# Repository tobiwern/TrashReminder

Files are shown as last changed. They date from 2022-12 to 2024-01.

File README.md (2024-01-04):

# Müll-Erinnerung ("Trash Reminder")

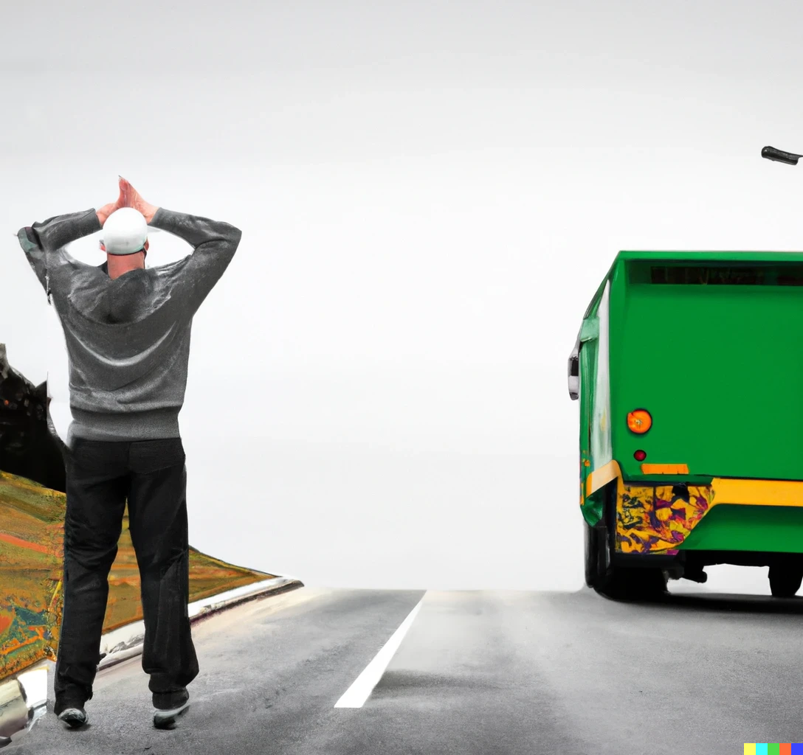
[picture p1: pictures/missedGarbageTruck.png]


**Schon mal vergessen den Mülleimer rauszustellen?**

`Müll-Erinnerung` erinnert Dich daran, indem es eine farbig blinkende Erinnerung anzeigt.

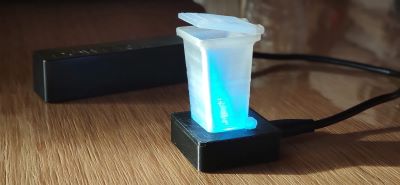
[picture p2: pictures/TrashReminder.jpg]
bild


Je nach Müllart blinkt das Mülleimermodell in einer unterschiedlichen Farbe:
- `weiß`: Restmüll
- `blau`: Papier
- `grün`: Biomüll/Häckselgut
- `gelb`: Gelber Sack oder Wertstofftonne

Wird also zum Beispiel `Restmüll` abgeholt, blinkt das Mülleimermodell `weiß`.

Sollten am selben Tag **zwei** unterschiedliche Müllarten abgeholt werden, wechselt das Licht zwischen den entsprechenden Farben hin und her. Also zum Beispiel zwischen `weiß` und `grün`, wenn sowohl `Restmüll` als auch `Biomüll` am selben Tag abgeholt werden.

## Einrichten der Müll-Erinnerung
Da das aktuelle Datum und Uhrzeit aus dem Internet ermittelt werden, muss die `Müll-Erinnerung` mit dem WLAN verbunden werden.

Wenn die `Müll-Erinnerung` zum ersten mal ans Netzteil angeschlossen wird, leuchetet das Mülleimermodell dauerhaft `rot` um mitzuteilen, dass die einmalige Einrichtung durchgeführt werden muss.

Hierzu muss man sich über das Smartphone mit dem WLAN Netzwerk `TrashReminder` verbinden und im folgenden Dialog
- Heimnetzwerk (SSID) auswählen und das
- Passwort für dieses Netzwerk eingeben.

Jetzt verbindet sich die `Müll-Erinnerung` mit dem ausgewählten Netzwerk und quittiert die erfolgreiche Verbindung mit einem `Feuerwerk` im Mülleimermodell.

Diese Einrichtung muss nur einmalig durchgeführt werden - von nun an holt sich die `Müll-Erinnerung` die aktuelle Uhrzeit aus dem Internet und gleicht diese mit eventuell vorliegenden Müllterminen ab, welche dann durch farbiges Blinken des Mülleimermodells mitgeteilt wird.

## Zeitpunkt der Erinnerung
Die Erinnerung erfolgt standardmäßig am **Vortag von 15 Uhr bis 9 Uhr morgens**. Diese Einstellung kann wie unter [Konfigurationsmodus](#konfigurationsmodus) beschrieben angepasst werden.

## Ausschalten der Erinnerung
Wenn der Müll rausgestellt wurde, kann die Erinnerung ausgeschaltet werden indem das **Mülleimermodell kurz angehoben** wird. Damit erlischt das Licht bis zur nächsten Abholerinnerung.

Wurde das Mülleimermodell versehentlich angehoben (aber der Müll nicht rausgestellt) kann man den Stecker der Stromversorgung einfach kurz aus- und wieder einstecken. Liegt eine Erinnerung vor und ist man im Erinnerungszeitraum (15 - 9 Uhr) blinkt das Mülleimermodell wieder wie zuvor.  

## Unterbrechung der WLAN Verbindung
Sollte es zu einer Verbindungsstörung zum Internet kommen, signalisiert die `Müll-Erinnerung` dies durch ein `schnelles rotes Blinken`. Man muss nichts weiter unternehmen - sobald die Verbindung wieder hergestellt werden kann wechselt die `Müll-Erinnerung` in den regulären Modus.

## Konfigurationsmodus
Um in den Konfigurationsmodus zu wechseln, muss das Mülleimermodell `dreimal angehoben` werden bis die LED dauerhaft `pink` leuchtet.
Jetzt kann über ein Smartphone oder einen Computer im Browser der Link [http://TrashReminder](http://TrashReminder) aufgerufen werden.
(In seltenen Fällen dauert es ein wenig, bis die Seite aufgerufen werden kann - in diesem Fall einfach die Seite erneut laden.)

Im Konfigurationsmodus können die folgenden Einstellungen für die `Müll-Erinnerung` vorgenommen werden:
- Start- und End-Uhrzeit der Erinnerung
- Abfallarten an die erinnert werden soll
- neue Abholtermine auf die `Müll-Erinnerung` laden

Außerdem werden die derzeit gültigen Abholtermine mit ihrer zugehörigen LED-Farbe angezeigt. Bereits verstrichene Termine werden ausgegraut dargestellt.

### Start- und End-Uhrzeit
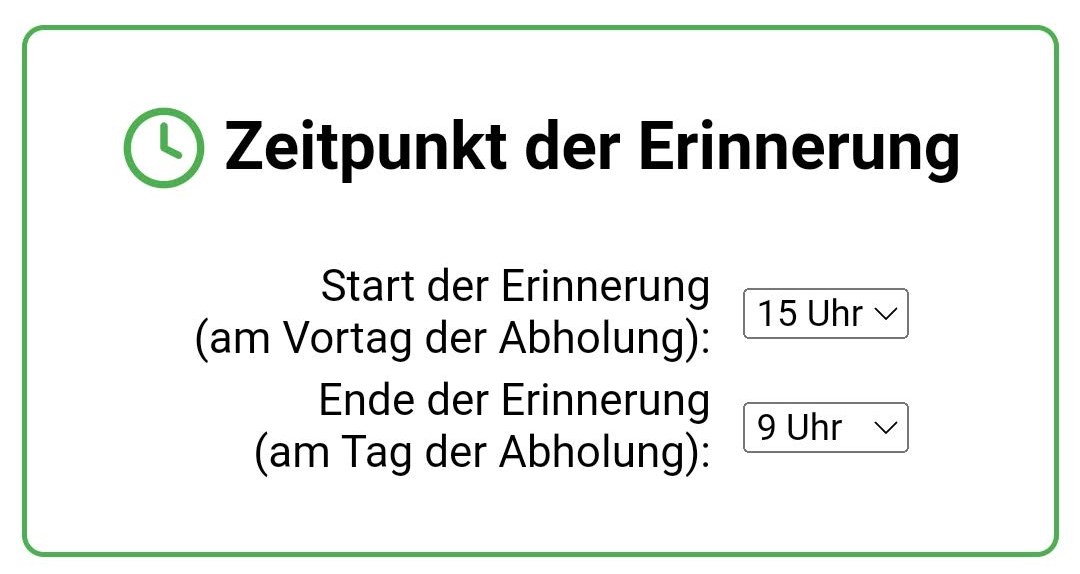
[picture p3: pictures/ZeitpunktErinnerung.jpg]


Standardmäßig ist
- der Start der Erinnerung auf **15 Uhr** am Vortag der Abholung
- das Ende der Erinnerung auf **9 Uhr** am Tag der Abholung 
gesetzt.
Der jeweilige Zeitpunkt kann über das Auswahlfeld eingestellt werden und wird sofort auf die `Müll-Erinnerung` übertragen.

### Auswahl der Abfallarten
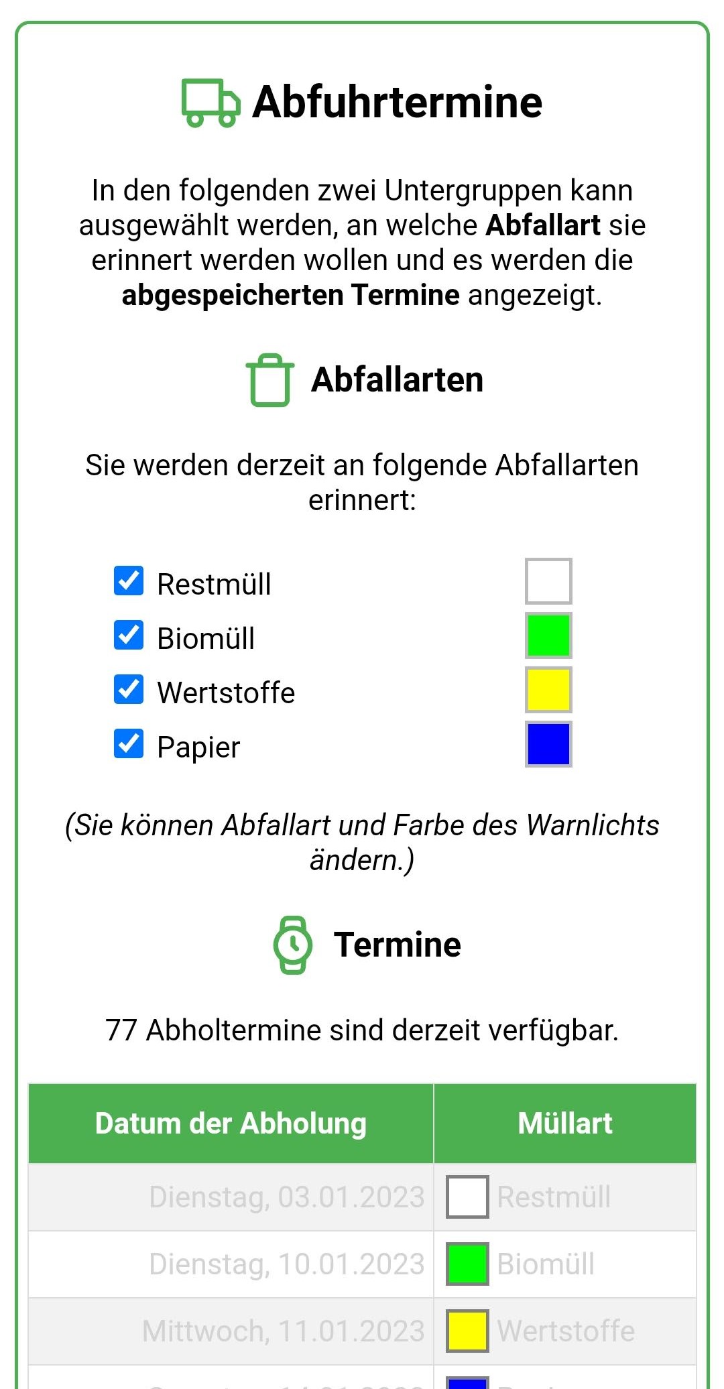
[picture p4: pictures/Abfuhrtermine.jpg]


Für die abgespeicherten Abholtermine kann eingestellt werden an **welche Abfallarten** erinnert werden soll. Ebenso kann hier auch die Farbe des Warnlichts eingestellt werden.

Jede Änderung der Auswahl wird sofort auf die `Müll-Erinnerung` geladen und die jeweils ausgewählten Einzeltermine entsprechend angezeigt.  

### Neue Abholtermine speichern
Falls sich Änderungen an den Abfuhrterminen ergeben haben oder Termine für das nächste Jahr gespeichert werden sollen, könnnen im [Konfigurationsmodus](#konfigurationsmodus) neue Abfuhrtermine auf die `Müll-Erinnerung` geladen werden. Hierbei werden die bestehenden Daten überschrieben! Sollten noch keine Abfuhrtermine gespeichert sein oder keine zukünftigen Termine mehr anstehen, wechselt die `Müll-Erinnerung` (ab Version 2024) automatisch in den Konfigurationsmodus.

Die Abfuhrdaten werden üblicherweise durch das Entsorgungsunternehmen auf einer Webseite im ICS Format angeboten und müssen zuerst heruntergeladen werden.

#### Beispiele für Müllentsorger
Beispiele für Unternehmen, bei denen ICS Dateien heruntergeladen werden können:

- `Hirrlingen`: https://www.abfall-kreis-tuebingen.de/online-abfuhrtermine/
- `Hirrlingen (Bogenschütz)`: https://www.bogenschuetz-entsorgung.de/blaue-tonne-tuebingen/abfuhrtermine.html
- `Neuweiler/Böblingen`: https://www.lrabb.de/start/Service+_+Verwaltung/Abfuhrtermine.html
- `Stuttgart`: https://service.stuttgart.de/lhs-services/aws/abfallkalender
- `Ebhausen`: https://www.awg-info.de/privatkunden/abfuhrtermine
- `Rheinbach`: https://www.rsag.de/abfallkalender/abfuhrtermine
- `Holzgerlingen`: https://www.awb-bb.de/start/entsorgen/Abfuhrtermine.html
- `Hannover`: https://www.aha-region.de/abholtermine/abfuhrkalender

#### Übertragen neuer Termine
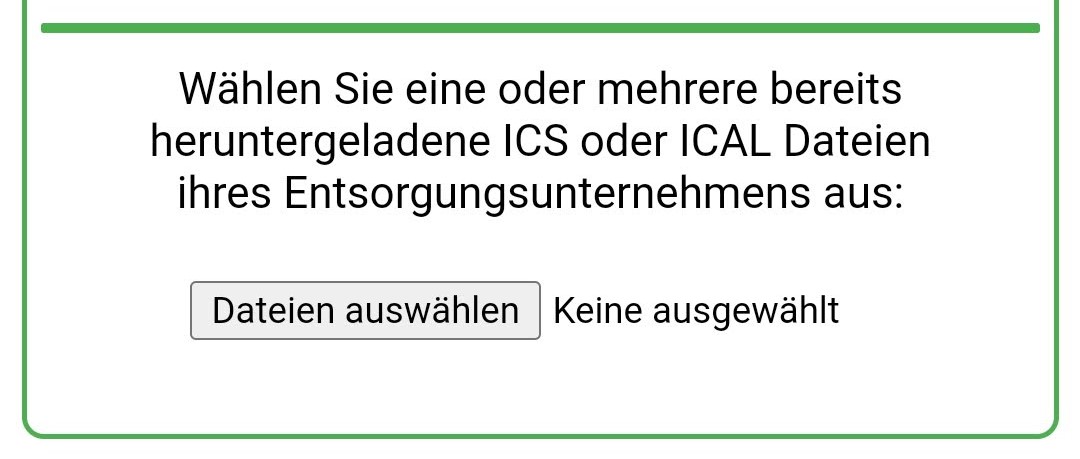
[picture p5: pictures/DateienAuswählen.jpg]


Sobald die ICS Datei auf das Handy oder den Computer heruntergeladen wurde, kann diese über den untenstehenden Button "Durchsuchen..." oder "Dateien auswählen" selektieren und auf die `Müll-Erinnerung` geladen werden. Es können auch mehrere Dateien ausgewählt werden, falls mehrere Unternehmen die Abfuhr übernehmen.

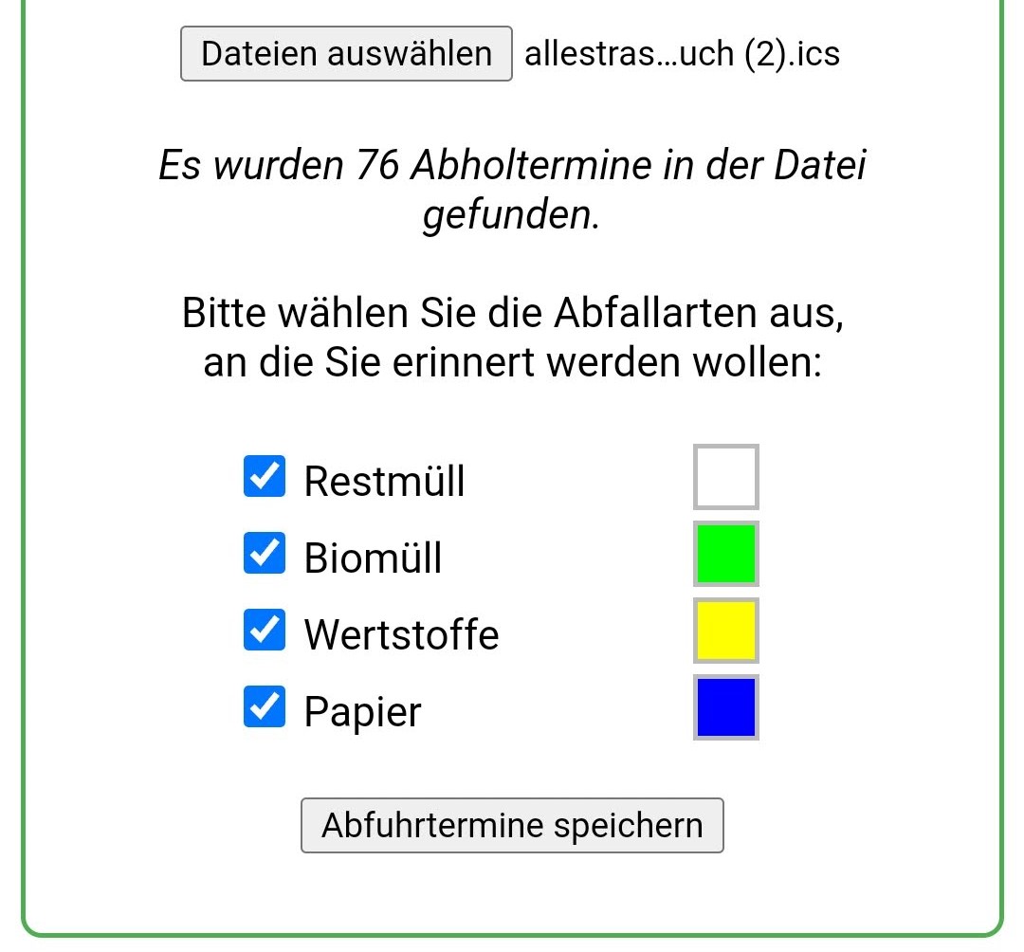
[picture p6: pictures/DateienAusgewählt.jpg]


Nach der Auswahl der Dateien werden die gefundenen Abfuhrarten mit der standardmäßigen Farbe des Warnlichts angezeigt. An welche Abfallarten erinnert werden soll sowie die Farbe des Warnlichst kann hier angepaßt werden.

Über den Button "Abfuhrttermine speichern" können nun die Termine auf die `Müll-Erinnerung` geladen werden. 

#### Keine zukünftigen Termine vorhanden
Liegen keine zukünftigen Termine mehr vor, signalisiert die `Müll-Erinnerung` dies durch ein `schnelles pinkes Blinken` und geht automatisch in den Konfigurationsmodus.

### Beenden des Konfigurationsmodus
Durch erneutes dreimaliges Anheben des Mülleimermodells kann der Konfigurationsmodus wieder verlassen werden. Dies wird durch ein Feuerwerk im Mülleimermodell bestätigt.
Nach 10 Minuten wird der Konfiguratonsmodus automatisch beendet.

## Problem Behandlung
- [http://TrashReminder](http://TrashReminder) wird nicht gefunden:
  - Du bist nicht im [Konfigurationsmodus](#konfigurationsmodus).
  - Versuche den Link über den Laptop oder ein anderes Smartphone aufzurufen.
  - Versuche einen anderen Browser (manche Browser lassen Verbindungen nicht über `http://` zu)
  - Ermittle die IP-Adresse (192.168.178.x oder ähnlich) der `Müll-Erinnerung` und gib sie  in das Browser-Suchfeld ein.
    - Rufe deine Router-Konfiguration (z.B. [http://fritz.box](http://fritz.box)) auf und suche die IP eines Gerätes mit Namen `ESP...`. 
    - Benutze eine Smartphone App wie [Fing](https://play.google.com/store/apps/details?id=com.overlook.android.fing) und suche die IP eines Gerätes mit Namen `ESP...`.  

## Autor
Tobias Werner, Erfindungen aller Art

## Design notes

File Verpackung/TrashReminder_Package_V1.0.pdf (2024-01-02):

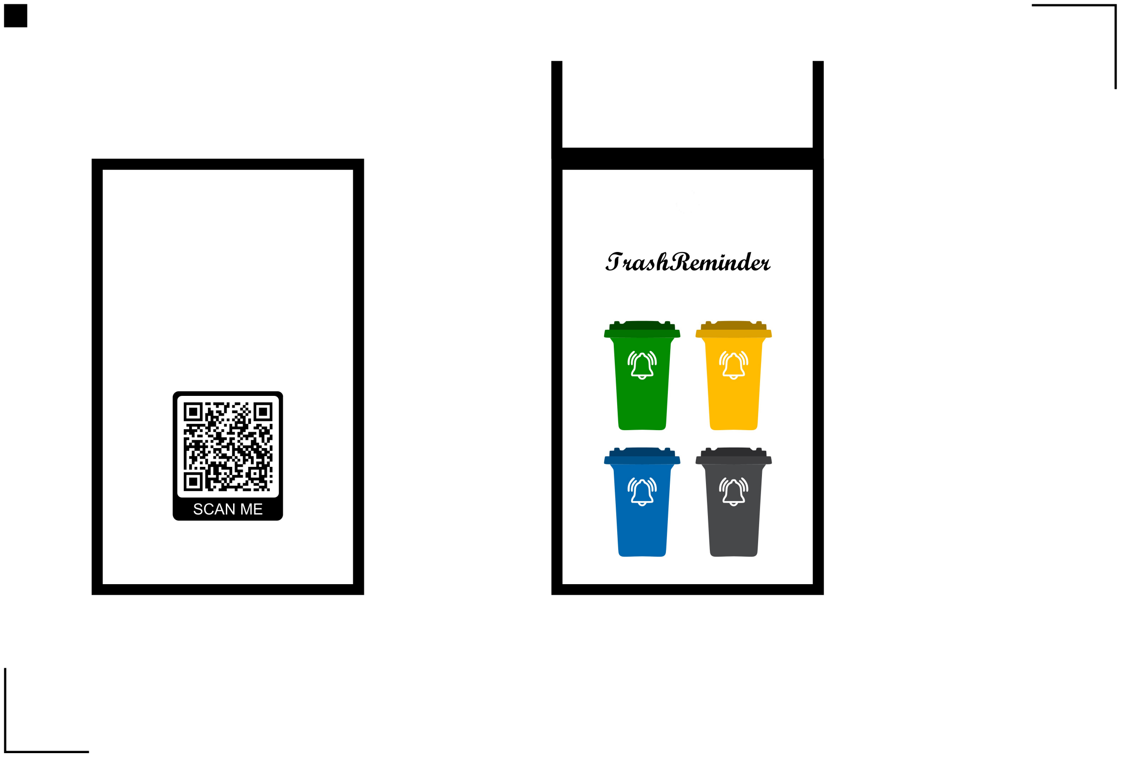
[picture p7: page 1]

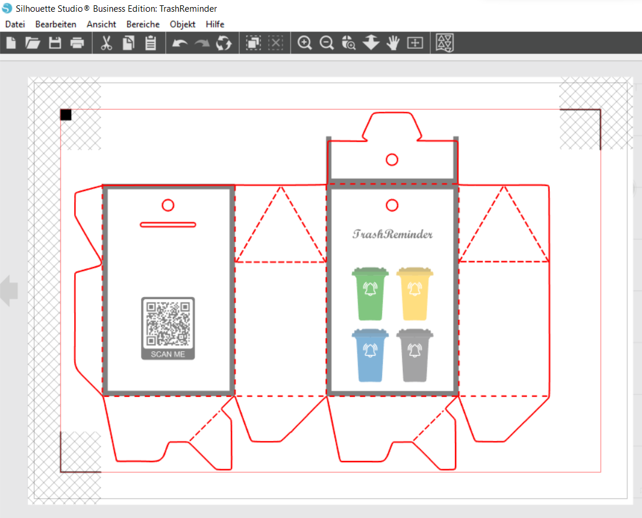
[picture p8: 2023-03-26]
Verpackung/Silhouette_Plot.png

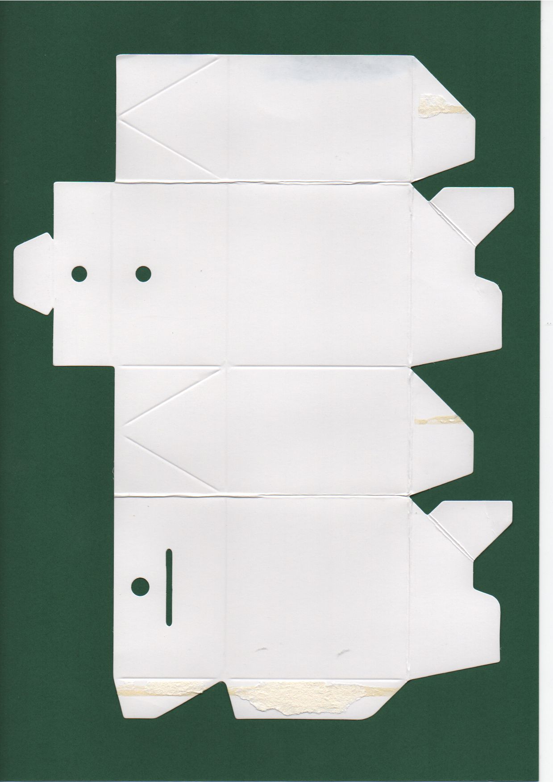
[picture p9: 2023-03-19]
Verpackung/haus.jpg

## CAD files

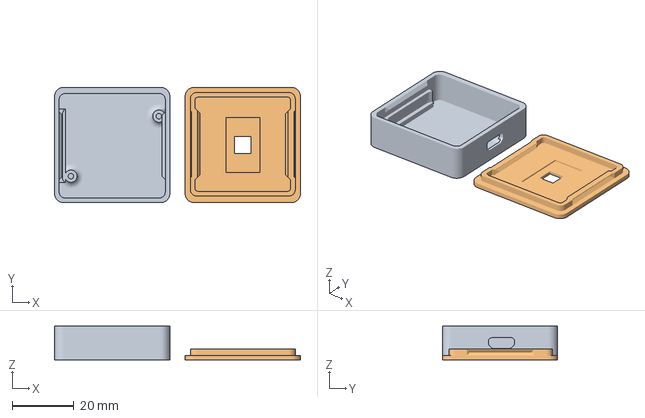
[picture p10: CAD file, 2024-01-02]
3D-Models/CE3_TrashReminder_Sockel.3mf
79.7 x 37.4 x 11.0 mm
Körper3.stl
CE3_Deckel.3mf

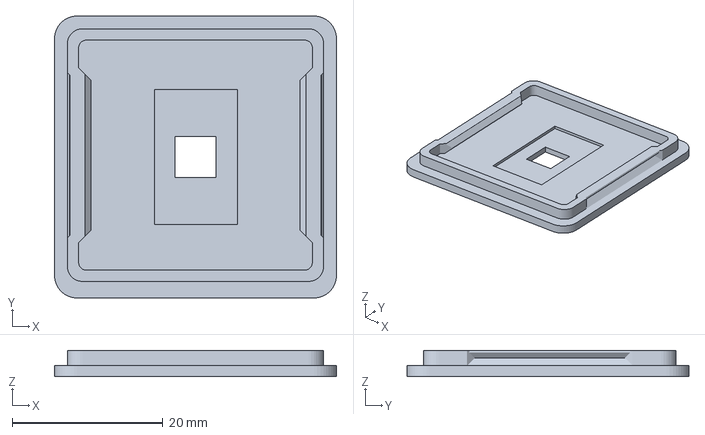
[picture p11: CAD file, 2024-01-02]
3D-Models/CE3_Deckel.3mf
37.4 x 37.4 x 3.50 mm

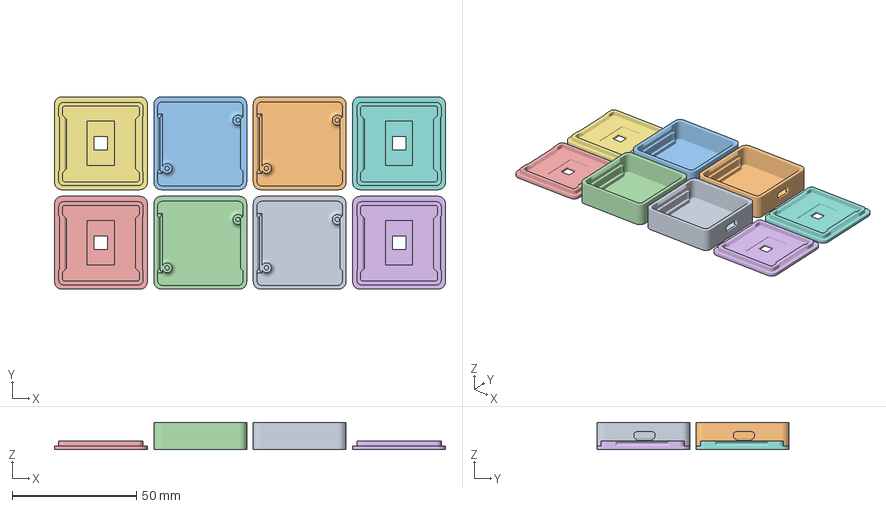
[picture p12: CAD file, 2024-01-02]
3D-Models/TrashReminder_Sockel4.3mf
157.4 x 77.4 x 11.0 mm
Körper3.stl
Körper3.stl(1)
Körper3.stl(2)
Körper3.stl(3)
CE3_Deckel.3mf(2)
CE3_Deckel.3mf(1)
CE3_Deckel.3mf(3)
CE3_Deckel.3mf(4)

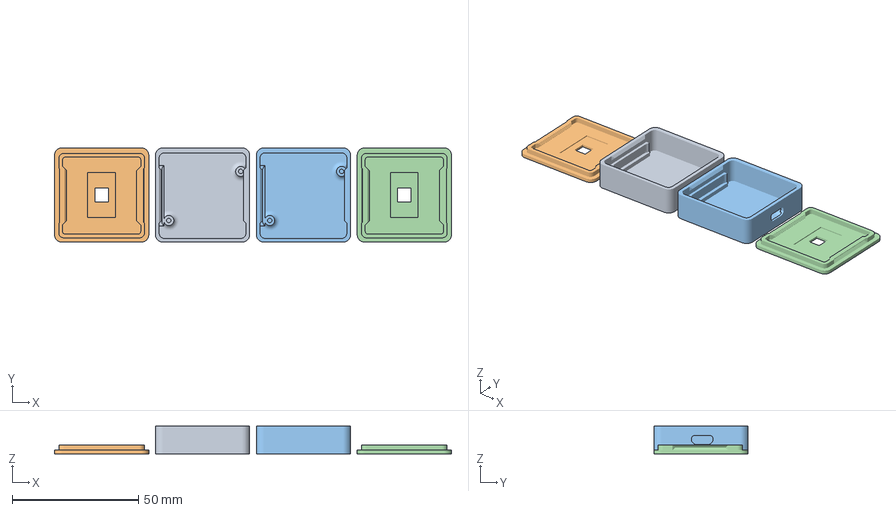
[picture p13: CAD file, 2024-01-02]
3D-Models/TrashReminder_Sockel2.3mf
157.4 x 37.4 x 11.0 mm
Körper3.stl(2)
CE3_Deckel.3mf(3)
Körper3.stl(1)
CE3_Deckel.3mf(4)

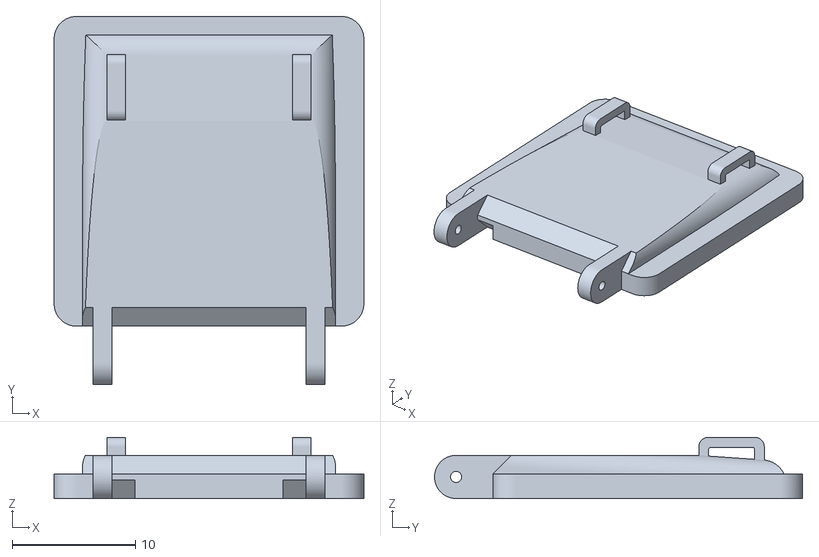
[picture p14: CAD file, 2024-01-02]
3D-Models/Deckel.stl
25.1 x 29.8 x 4.96

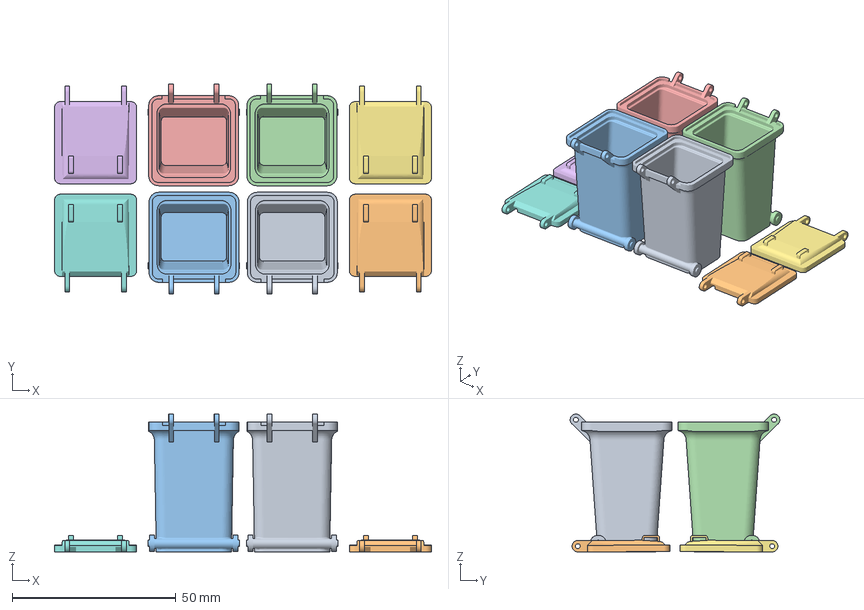
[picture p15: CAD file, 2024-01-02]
3D-Models/TrashReminder_Tonne4.3mf
115.1 x 64.0 x 42.1 mm
Tonne.stl
CE3_Deckel.3mf
Tonne.stl(1)
Tonne.stl(2)
Tonne.stl(3)
CE3_Deckel.3mf(1)
CE3_Deckel.3mf(2)
CE3_Deckel.3mf(3)

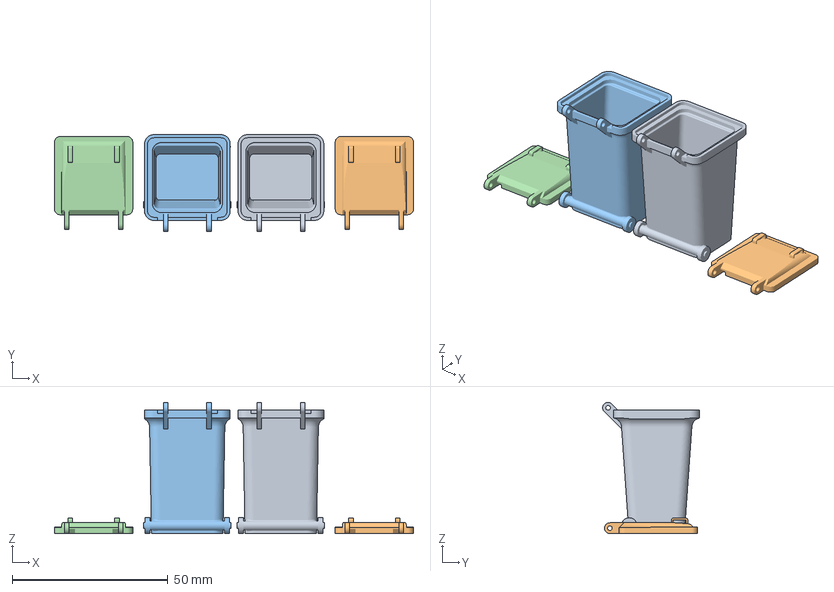
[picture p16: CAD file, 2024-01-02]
3D-Models/TrashReminder_Tonne2.3mf
115.1 x 31.0 x 42.1 mm
Tonne.stl
CE3_Deckel.3mf
Tonne.stl(1)
CE3_Deckel.3mf(3)

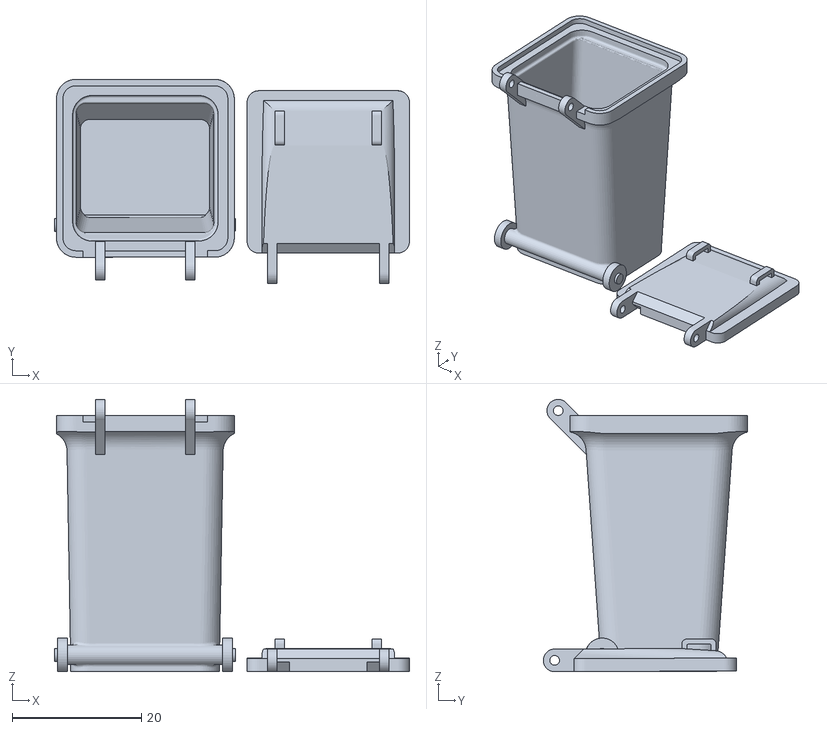
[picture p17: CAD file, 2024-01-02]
3D-Models/Tonne&Deckel_2023.09.06.stl
54.9 x 31.6 x 42.1

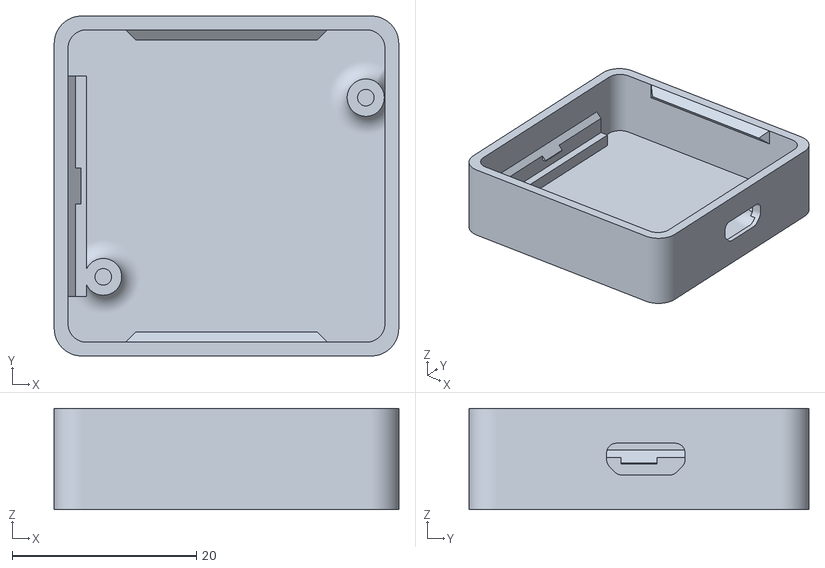
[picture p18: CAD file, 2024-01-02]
3D-Models/Gehäuse.stl
37.4 x 36.9 x 11.0

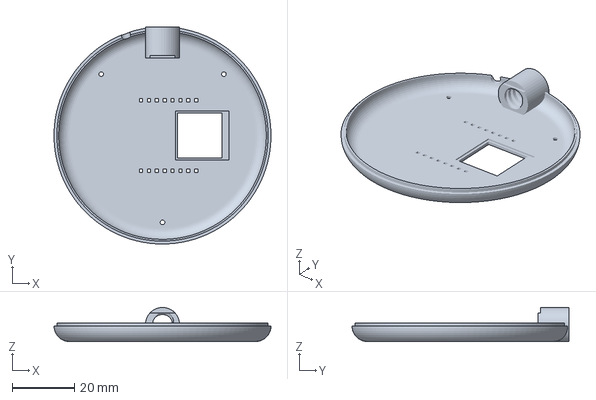
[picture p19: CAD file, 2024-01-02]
3D-Models/CE3_Gehäuse unten.3mf
70.0 x 70.0 x 11.0 mm

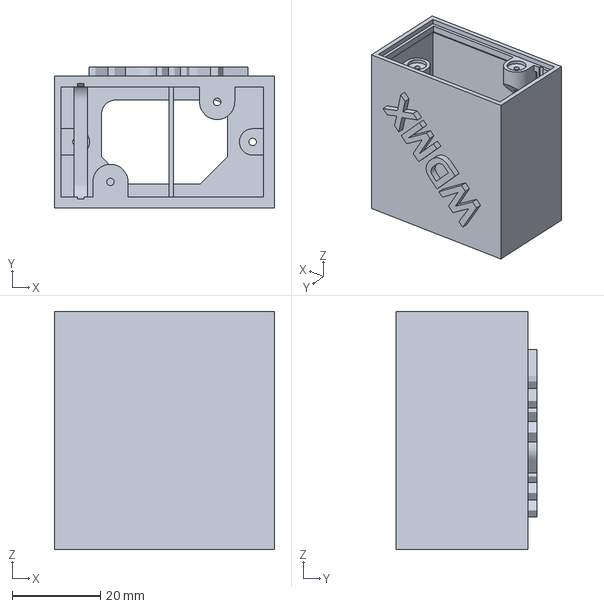
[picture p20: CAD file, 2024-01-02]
3D-Models/CE3_Gehäuse.3mf
50.0 x 32.0 x 54.0 mm

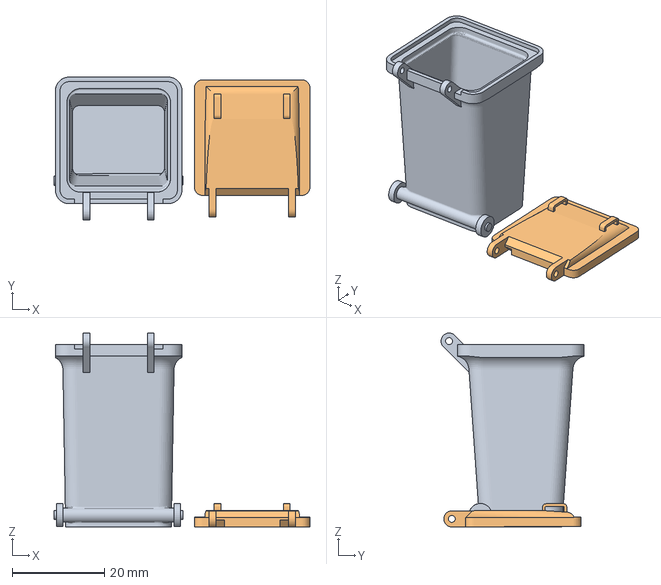
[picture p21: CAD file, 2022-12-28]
3D-Models/TrashReminder_Tonne.3mf
55.6 x 31.0 x 42.1 mm
Tonne.stl
CE3_Deckel.3mf

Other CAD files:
3D-Models/TrashReminder_Sockel.3mf
3D-Models/ESP8266_Housing_LED v45.f3d

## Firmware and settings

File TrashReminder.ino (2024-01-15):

/*
Todo:
- Show Firmware Version in Webpage!
- Sleep when there are no events in the next days
- Contact time server less often and maintain time internally (possible? => can we detect if the device returns from sleep or gets replugged? yes)
- query API directly instead of hard-coded list
- check if there are more tasksPerDay then allowed
- Add magnets to trashcan so it snapps in place
- Allow in settings to define a different time zone
- Always start the server, detect when a device is connected => purple
- Selecting a color in the config should be shown directly on the model
- Ending configuration mode via model closes the website
- Acknowledge via model OR website
- Should we have a logFile that is overwritten when running out of space? Could help debug - Or have a "Send/Delete Logfile" option in the GUI 
- NTP Time Server: What happens if it can not be reached? =>  isTimeSet(), https://github.com/arduino-libraries/NTPClient/blob/master/NTPClient.h
  - Switch epochTime to unsigned long
  - update() =>  @return true on success, false on failure
Helpful:
Epoch Converter: https://www.epochconverter.com/
JSON Validator: https://jsonformatter.curiousconcept.com/#
*/

#include <ESP8266WiFi.h>
#include <NTPClient.h>
#include <WiFiUdp.h>
#include <WiFiManager.h>  // https://github.com/tzapu/WiFiManager

#include "filesystem.h"
#include "webpage.h"

//forward function prototypes (so function order does not matter)
//void setColor(int color, boolean fade, int blinkSpeed);

const int maxNumberOfTasksPerDay = 4;
int colorIds[maxNumberOfTasksPerDay];
int colorIdsLast[maxNumberOfTasksPerDay];
int colorIndex = 0;  //used to toggle between multiple colors for same day tasks

int startHour = 15;                  //am Vortag
int endHour = 8;                     //am Abholugstag
int brightness = 255;                //highest value since used to fadeBy...
int fadeAmount = 5;                  // Set the amount to fade to 5, 10, 15, 20, 25 etc even up to 255.
int showDuration = 5000;             //ms Splash screen
int configTimeout = 10 * 60 * 1000;  //10 minutes
unsigned long millisLast = 0;

/// STATE MACHINE
#define STATE_INIT 0
#define STATE_SHOW 1
#define STATE_DISCONNECTED 2
#define STATE_QUERY 3
#define STATE_CONFIGURE 4
#define STATE_DEMO 5
#define STATE_NODATES 6

int STATE = STATE_INIT;
//int STATE = STATE_DEMO;
int STATE_PREVIOUS = -1;
int STATE_NEXT = -1;
int STATE_FOLLOWING = -1;
String stateTbl[] = { "STATE_INIT", "STATE_SHOW", "STATE_DISCONNECTED", "STATE_QUERY", "STATE_CONFIGURE", "STATE_DEMO", "STATE_NODATES" };

#include <FastLED.h>
#define NUM_LEDS 1
#define DATA_PIN 4  //D2
#define BRIGHTNESS 0
#define FRAMES_PER_SECOND 120
CRGB leds[NUM_LEDS];
uint8_t gHue = 0;  // rotating "base color" used by many of the patterns

//Switch
#include <Button.h>
#define REED_PIN 5  //D1
Button reed(REED_PIN, LOW, BTN_PULLUP, LATCHING);
int switchCounter = 0;
int multiClickTimeout = 1000;  //ms
unsigned long lastSwitchMillis = 0;

int acknowledge = 0;   //turn off reminder light when the Mülleimer is lupft
int triggerEpoch = 0;  //used to detect if the epochDict is changing => reset acknowledge
int initialized = 0;   //in order to prevent acknowledge to be triggered at the beginning

// Define NTP Client to get time
WiFiUDP ntpUDP;
NTPClient timeClient(ntpUDP, "pool.ntp.org");
unsigned int nowEpoch = 0;   //global since only querying every minute
int queryIntervall = 60000;  //ms => every minute (could be less, however to really turn on LED at intended time...)
unsigned long lastQueryMillis = 0;
int timeEpochLast = -1;
int maxTimeEpochDelta = 60 * 60;  //in seconds => 1 hour difference
//data
const char* dataFile = "/data.json";
const char* settingsFile = "/settings.json";
int numberOfValidTaskIds = 0;  //global counter
int numberOfTaskIds = 0;       //global counter
int numberOfEpochs = 0;        //global counter
const int maxNumberOfEpochs = 200;
const int maxNumberOfTaskIds = 20;

String task[maxNumberOfTaskIds];
int color[maxNumberOfTaskIds];
int validTaskId[maxNumberOfTaskIds];

typedef struct epochTask {
  unsigned int epoch;
  int taskIds[maxNumberOfTasksPerDay];
} epochTask;

epochTask epochTaskDict[maxNumberOfEpochs];

// DEMO
int demoCurrTask = 0;
const int demoNumberOfTasks = 5;
epochTask demoTaskDict[demoNumberOfTasks];
int offDuration = 5 * 1000;  // 5 sec after trashcan was lifted the blinking starts again

void setup() {
  Serial.begin(115200);
  while (!Serial) { ; }
  reed.attachEdgeDetect(doNothing, setAcknowledge);
  FastLED.addLeds<WS2812B, DATA_PIN, GRB>(leds, NUM_LEDS);  // GRB ordering is typical
  delay(200);
  leds[0] = CRGB::Red;  //in case no successful WiFi connection
  FastLED.show();
  WiFiManager wm;
  //  wm.resetSettings();
  if (wm.autoConnect("TrashReminder")) {
    Serial.println("Successfully connected.");
  } else {
    Serial.println("Failed to connect.");
  }
  WiFi.hostname("TrashReminder");
  //Time Client
  timeClient.begin();
  timeClient.setTimeOffset(3600);  //in seconds GMT+2 Berlin, GMT-4 NY => -3600*4
  //  deleteFile(dataFile);
}

void loop() {
  handleState();
}

// ESP Functions
void handleConnection() {
  if (!WiFi.isConnected()) {
    Serial.println("Connection lost!");
    STATE_NEXT = STATE_DISCONNECTED;
  }
}

int getDominantTimeEpoch(int repeat) {
  int timeEpoch[repeat];
  for (int i = 0; i < repeat; i++) {
    timeEpoch[i] = getTimeEpoch();
    Serial.println("timeEpoch" + String(i) + ": " + String(timeEpoch[i]));
    delay(100);
  }
  int sum = 0;
  for (int i = 0; i < repeat; i++) {
    sum += timeEpoch[i];
  }
  int average = int(sum / float(repeat));
  int minDeviation = abs(average - timeEpoch[0]);
  int dominantTimeEpoch = timeEpoch[0];
  for (int i = 1; i < repeat; i++) {
    if (abs(average - timeEpoch[i]) < minDeviation) { dominantTimeEpoch = timeEpoch[i]; }  //pick timeEpoch with least deviation to the average of all timeEpochs
  }
  Serial.println("dominantTimeEpoch: " + String(dominantTimeEpoch));
  timeEpochLast = dominantTimeEpoch; //since this is considered correct
  return (dominantTimeEpoch);
}

int getTimeEpoch() {
  int timeEpoch = 0;
  while (timeEpoch < 1705261183) {  //an old time stamp is not possible
    timeClient.update();
    timeEpoch = timeClient.getEpochTime();
//    Serial.println("timeEpoch: " + String(timeEpoch));
  }
  return (timeEpoch);
}

int getCurrentTimeEpoch() {
  int timeEpoch = getTimeEpoch();
  if (abs(timeEpoch - timeEpochLast) > maxTimeEpochDelta) {
    Serial.println("WARNING: There was a glitch on the NTP Time Server! Last time: " + String(timeEpochLast) + ", current time: " + String(timeEpoch) + ". Repeating query!");
    timeEpoch = getDominantTimeEpoch(3);
  }
  timeEpochLast = timeEpoch;
  return (timeEpoch);  //sometimes receives too large timestamp
}

void printColorIds() {  //debug
  for (int i = 0; i < maxNumberOfTasksPerDay; i++) {
    Serial.println("colorIds[" + String(i) + "] = " + String(colorIds[i]));
  }
}

void handleLed(unsigned int nowEpoch) {
  int dictEpoch;
  boolean futureDatesExist = false;
  memset(colorIds, -1, sizeof(colorIds));
  //  printColorIds();
  for (int i = 0; i < numberOfEpochs; i++) {  //numberOfEpochs is initialized in function initDateFromFile()
    dictEpoch = epochTaskDict[i].epoch;
    if ((nowEpoch > dictEpoch + (startHour - 24) * 60 * 60) && (nowEpoch < dictEpoch + endHour * 60 * 60)) {
      //      Serial.println("nowEpoch: " + String(nowEpoch) + ", dictEpoch = " + String(dictEpoch) + ", dictEpoch+startTime = " + String(dictEpoch + (startHour - 24) * 60 * 60) + ", dictEpoch+endTime = " + String(dictEpoch + endHour * 60 * 60));
      if (dictEpoch != triggerEpoch) {
        acknowledge = 0;  //acknowledge only valid for same triggerEpoch
        colorIndex = 0;
        Serial.println("Resetting since new trigger!");
      }
      triggerEpoch = dictEpoch;
      if (!acknowledge) {
        setColorIds(epochTaskDict[i].taskIds);
      }
    }
    if (nowEpoch <= dictEpoch) { futureDatesExist = true; }
  }
  if (!futureDatesExist) {  //ToDo: We should count the occurances if the no futureDatesExist (once the lastEpochTime changes) - if this is higher than max => Go into the STATE_NODATES
    millisLast = millis();
    if (numberOfEpochs > 0) {      //if no more dates exists
      STATE_NEXT = STATE_NODATES;  //to reach this state: a) really no more dates exist b) invalid date send (nowEpoch wrong)
    } else {                       //initial setup
      STATE_NEXT = STATE_CONFIGURE;
    }
  }
  //printColorIds();
  setTaskColor();
  FastLED.show();
}

boolean isValidTask(int taskId) {
  for (int i = 0; i < numberOfValidTaskIds; i++) {
    if (taskId == validTaskId[i]) { return (true); }
  }
  return (false);
}

void setColorIds(int taskIds[]) {
  int index = 0;
  //  Serial.println("==================");
  for (int i = 0; i < maxNumberOfTasksPerDay; i++) {
    //    Serial.println("taskId[" + String(i) + "] = " + String(int(taskIds[i])) + ", valid = " + String(isValidTask(taskIds[i])));
    if (taskIds[i] != -1) {
      //Serial.println("taskId = " + String(taskIds[i]));
      if (isValidTask(taskIds[i])) { colorIds[index++] = int(taskIds[i]); }
    }
  }
}

void handleReed() {
  reed.update();
  initialized = true;
}

void setAcknowledge() {
  unsigned long now = millis();
  if (initialized) {
    Serial.println("OFF - Acknowedge!");
    acknowledge = 1;
    //Multi-click detection
    switchCounter++;
    if (((now - lastSwitchMillis) > multiClickTimeout) || (lastSwitchMillis == 0)) { switchCounter = 0; }
    //    Serial.println("Counter = " + String(switchCounter));
    lastSwitchMillis = now;
    if (STATE != STATE_DEMO) {
      if (switchCounter == 2) {
        if (STATE == STATE_CONFIGURE) {
          STATE_NEXT = STATE_INIT;  //reset
        } else {
          STATE_NEXT = STATE_CONFIGURE;
        }
      }
    }
  }
}

void doNothing() {
  //  Serial.println("ON");
  true;
}

void incrementColorId() {
  int numberOfTasks = 0;
  for (int i = 0; i < maxNumberOfTasksPerDay; i++) {  //detect how many tasks
    if (colorIds[i] != -1) { numberOfTasks++; }
  }
  colorIndex++;
  if (colorIndex >= numberOfTasks) { colorIndex = 0; }
  //  Serial.println("colorIndex = " + String(colorIndex) + ", numberOfTasks = " + String(numberOfTasks) + ", maxNumberOfTasksPerDay = " + String(maxNumberOfTasksPerDay));
}

void setBrightness(int blinkSpeed = 20, boolean reset = false) {
  if (reset) {
    brightness = 255;
  } else {
    if ((colorIds[0] != colorIdsLast[0]) || (colorIds[1] != colorIdsLast[1])) { brightness = 255; }
    colorIdsLast[0] = colorIds[0];
    colorIdsLast[1] = colorIds[1];
  }
  leds[0].fadeLightBy(brightness);
  brightness = brightness + fadeAmount;
  if (brightness <= 0) { brightness = 0; }
  if (brightness >= 255) {
    brightness = 255;
    incrementColorId();
  }
  //    Serial.println("Brightness = " + String(brightness) + ", ColorIndex = " + String(taskId));
  if (brightness <= 0 || brightness >= 255) { fadeAmount = -fadeAmount; }
  delay(blinkSpeed);
}

void setTaskColor() {
  if (colorIds[0] == -1) {
    //    Serial.println("No Event");
    leds[0] = CRGB::Black;
  } else {
    // EVENT
    //    Serial.println("Event: " + task[taskId] + " => LED = " + String(color[taskId],HEX));
    leds[0] = color[colorIds[colorIndex]];
    setBrightness();
  }
}

void setColor(int color, boolean fade = true, int blinkSpeed = 20) {
  leds[0] = color;
  if (fade) { setBrightness(blinkSpeed); }
  FastLED.show();
}

/// Splash Screen
void rainbow() {
  // FastLED's built-in rainbow generator
  fill_rainbow(leds, NUM_LEDS, gHue, 7);
}

void rainbowWithGlitter() {
  // built-in FastLED rainbow, plus some random sparkly glitter
  rainbow();
  addGlitter(50);
}

void addGlitter(fract8 chanceOfGlitter) {
  if (random8() < chanceOfGlitter) {
    leds[random16(NUM_LEDS)] += CRGB::White;
  }
}

#include "webserver.h"  //separate file for webserver functions

/* //DEBUG
boolean initDataFromFile() {
  numberOfValidTaskIds = 4;
  validTaskId[0] = 0;
  validTaskId[1] = 1;
  validTaskId[2] = 2;
  validTaskId[3] = 3;
  numberOfTaskIds = 4;
  task[0] = "Biomüll";
  task[1] = "Papier";
  task[2] = "Restmüll";
  task[3] = "Wertstoffe";
  color[0] = 0x00FF00;
  color[1] = 0x0000FF;
  color[2] = 0xFFFFFF;
  color[3] = 0xFFFF00;
  numberOfEpochs = 2;
  epochTask entry0 = {.epoch = 1674000000, .taskIds = {2,1,-1,-1} };
  epochTaskDict[0] = entry0;
  epochTask entry1 = {.epoch = 1674518400, .taskIds = {0,-1,-1,-1} };
  epochTaskDict[1] = entry1;
  return (true);
}
*/
void setDemoConfig() {
  acknowledge = 0;  //acknowledge only valid for same triggerEpoch
  colorIndex = 0;
  demoCurrTask = 0;
  numberOfValidTaskIds = 4;
  validTaskId[0] = 0;
  validTaskId[1] = 1;
  validTaskId[2] = 2;
  validTaskId[3] = 3;
  numberOfTaskIds = 4;
  task[0] = "Restmüll";
  task[1] = "Wertstoffe";
  task[2] = "Biomüll";
  task[3] = "Papier";
  color[0] = 0xFFFFFF;
  color[1] = 0xFFFF00;
  color[2] = 0x00FF00;
  color[3] = 0x0000FF;
  demoTaskDict[0] = { .epoch = 0, .taskIds = { 0, -1, -1, -1 } };  //Rest
  demoTaskDict[1] = { .epoch = 1, .taskIds = { 1, -1, -1, -1 } };  //Gelber Sack
  demoTaskDict[2] = { .epoch = 2, .taskIds = { 2, -1, -1, -1 } };  //Bio
  demoTaskDict[3] = { .epoch = 3, .taskIds = { 3, -1, -1, -1 } };  //Papier
  demoTaskDict[4] = { .epoch = 4, .taskIds = { 2, 3, -1, -1 } };   //Papier, Bio
  setColorIds(demoTaskDict[demoCurrTask].taskIds);
}

void handleState() {
  unsigned long millisNow = millis();
  STATE_NEXT = -1;
  // Serial.println("STATE = " + stateTbl[STATE] + ", STATE_PREVIOUS = " + stateTbl[STATE_PREVIOUS]);
  if (STATE != STATE_PREVIOUS) { Serial.println("STATE = " + stateTbl[STATE]); }
  switch (STATE) {
    case STATE_INIT:  //***********************************************************
      if (STATE_PREVIOUS == STATE_CONFIGURE) { stopWebServer(); }
      millisLast = millisNow;
      brightness = 255;
      colorIndex = 0;
      acknowledge = 0;
      memset(colorIds, -1, sizeof(colorIds));
      memset(colorIdsLast, -1, sizeof(colorIdsLast));
      //      listDir("/"); //ToDo1
      initStartEndTimes();  //initializes startHour and endHour
      initDataFromFile();
      nowEpoch = getDominantTimeEpoch(3);  //making sure that the very first time stamp is correct
      STATE_NEXT = STATE_SHOW;
      break;
    case STATE_SHOW:  //***********************************************************
      rainbowWithGlitter();
      FastLED.show();
      // insert a delay to keep the framerate modest
      FastLED.delay(1000 / FRAMES_PER_SECOND);
      // do some periodic updates
      EVERY_N_MILLISECONDS(20) {
        gHue++;
      }  // slowly cycle the "base color" through the rainbow
      if ((millisNow - millisLast) > showDuration) {
        if (STATE_FOLLOWING != -1) {
          STATE_NEXT = STATE_FOLLOWING;
          STATE_FOLLOWING = -1;
        } else {
          STATE_NEXT = STATE_QUERY;
        }
      }
      break;
    case STATE_DISCONNECTED:  //***********************************************************
      setColor(CRGB::Red, true, 2);
      if (WiFi.isConnected()) { STATE_NEXT = STATE_INIT; }
      break;
    case STATE_QUERY:  //***********************************************************
      if (((millisNow - lastQueryMillis) > queryIntervall) || (lastQueryMillis == 0)) {
        nowEpoch = getCurrentTimeEpoch();
        Serial.println("Received current epoch time: " + String(nowEpoch));
        lastQueryMillis = millisNow;
      }
      handleLed(nowEpoch);
      handleReed();
      handleConnection();
      break;
    case STATE_NODATES:  //***********************************************************
    case STATE_CONFIGURE:
      if (STATE_PREVIOUS != STATE_CONFIGURE) { millisLast = millisNow; }
      if (!serverRunning) { startWebServer(); }
      if (STATE == STATE_NODATES) {
        setColor(CRGB::Purple, true, 2);
      } else {
        setColor(CRGB::Purple, false);
      }
      server.handleClient();
      handleReed();
      if (millisNow - millisLast > configTimeout) { STATE_NEXT = STATE_INIT; }  //TimeOut
      break;
    case STATE_DEMO:
      if (STATE_PREVIOUS != STATE_DEMO) {
        Serial.println("Setting Demo Config");
        acknowledge = 0;
        setDemoConfig();
      }
      if (!acknowledge) {
        setTaskColor();
      } else {
        setColor(CRGB::Black, false);
      }
      FastLED.show();
      if (acknowledge && ((millisNow - lastSwitchMillis) > offDuration)) {
        demoCurrTask++;
        colorIndex = maxNumberOfTasksPerDay;
        if (demoCurrTask >= demoNumberOfTasks) { demoCurrTask = 0; }
        Serial.println("Setting demoCurrTask = " + String(demoCurrTask));
        memset(colorIds, -1, sizeof(colorIds));
        setColorIds(demoTaskDict[demoCurrTask].taskIds);
        acknowledge = 0;
      }
      handleReed();
      break;
    default:
      break;
  }
  STATE_PREVIOUS = STATE;
  if (STATE_NEXT != -1) { STATE = STATE_NEXT; }
}

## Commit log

2022-12-21 TestLEDs,WifiManager, Tasks+, ColorHex,15-8,FastLed
    [CE3_Tonne.3mf, ESP8266_Housing_LED.3mf]
2022-12-21 3D files
    [CE3_Deckel-ESP.3mf, CE3_Deckel.3mf]
2022-12-21 ToDo and new case
    [ESP8266_Housing_LED.3mf]
2022-12-22 smaller USB, Tighter Cover
    [CE3_Deckel-ESP.3mf, ESP8266_Housing_LED.3mf]
2022-12-22 BugFix: Warn one day before!
    [TrashReminder.ino]
2022-12-22 STATE_CONFIGURE new
    only blinking LED for the moment
2022-12-22 Reset Brightness in INIT
    [TrashReminder.ino]
2022-12-22 More docu, commented wm.reset
    [TrashReminder.ino]
2022-12-23 Minor updates
    [CE3_Deckel-ESP.3mf, TrashReminder.3mf]
2022-12-23 Cleanup files
    [CE3_Deckel-ESP.3mf, CE3_Deckel.3mf, ESP8266_Housing_LED.3mf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]
2022-12-23 Updated correct temperatures, no brim and no support
    [TrashReminder_Sockel.3mf, TrashReminder_Tonne.3mf]
2022-12-23 BugFix: IncrementColorId did not work correctly
    [TrashReminder.ino]
2022-12-25 preparing multiple same epochTime in data
    ...however unordered_map does not support. Need to switch to array
2022-12-28 revert back: multiple table entries with same key is of course not possible
    [TrashReminder.ino]
2022-12-28 Updated model to require less rework
    [TrashReminder_Tonne.3mf]
2022-12-30 Updated ESP click-in
    [TrashReminder_Sockel.3mf]
2023-01-01 Update TrashReminder_Sockel.3mf
    Increased snap-in for ESP
    [TrashReminder_Sockel.3mf]
2023-01-02 mount/unmount before every FS opertion
    Seems to work more stable
2023-01-08 readEnd/StartTimes new, resetting millisLast for Feuerwerk
2023-01-09 ReadFile: Switched to ReadString
2023-01-10 Fixed error with epoch and simplified JSON fomat
    getTime() returns milliseconds. we need seconds => /1000
2023-01-12 Reading data from file no longer from .h
    memory optimization. Getting rid of strings, using char instead of int, etc.
    [TrashReminder.ino]
2023-01-12 char => int: Fixed color problem
    Increased number of tasks to 20
    printColorIds: using maxNumberOfTaskIds
    no more including
    validIndex => validTaskIds
    [TrashReminder.ino]
2023-01-13 Since genCheckboxesText function code no longer works
    [TrashReminder.ino]
2023-01-13 Renamed to show up in Arduino IDE
2023-01-15 Refresh "current dates" after a successful upload of new dates
2023-01-15 separating buttons
2023-01-15 Message Functions, buttonMessage
2023-01-15 Button active
2023-01-15 button hover + active
2023-01-17 Reading settings directly from file
    Seems like the reed was the problem...
    [TrashReminder.ino]
2023-01-18 Revert "Merge pull request #3 from tobiwern/Reading-JSON"
    This reverts commit 62f3bccc500700cbbea5d459ad96c32411c7f0ae, reversing
    changes made to b4c34c8243210997f3d6adf575aac56cb492ce09.
    [TrashReminder.ino]
2023-01-18 Moved 3D-Models and PythonHelpers
    [TrashReminder_Sockel.3mf, TrashReminder_Tonne.3mf]
2023-01-27 Removed button
2023-09-27 Latest Models
    [ESP8266_Housing_LED v45.f3d]
2024-01-02 Before no more dates warning
    [CE3_Deckel.3mf, CE3_Gehäuse unten.3mf, CE3_Gehäuse.3mf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]
2024-01-15 Detect & Correct invalid timeEpoch values
    getDominantTimeEpoch: new
    getTimeEpoch: new
    [TrashReminder.ino]
2024-01-15 Upgraded to ArduinoJson 7
